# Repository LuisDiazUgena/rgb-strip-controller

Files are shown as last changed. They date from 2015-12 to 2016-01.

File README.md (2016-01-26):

# rgb-strip-controller

Rgb strip controller for WS2812 led stripes like Adafruit Neopixel.

Please check out <a href="#updates">updates</a> below.

# Hardware

It uses an Attiny 84 to run the code and a HC-06 bluetooth module to communicate with Bluetooth with an [app](https://github.com/LuisDiazUgena/Hack-A-Lamp/).

You can find a production board in [Hardware/For Manufacturing folder](https://github.com/LuisDiazUgena/rgb-strip-controller/tree/master/Hardware/For%20manufacturing)

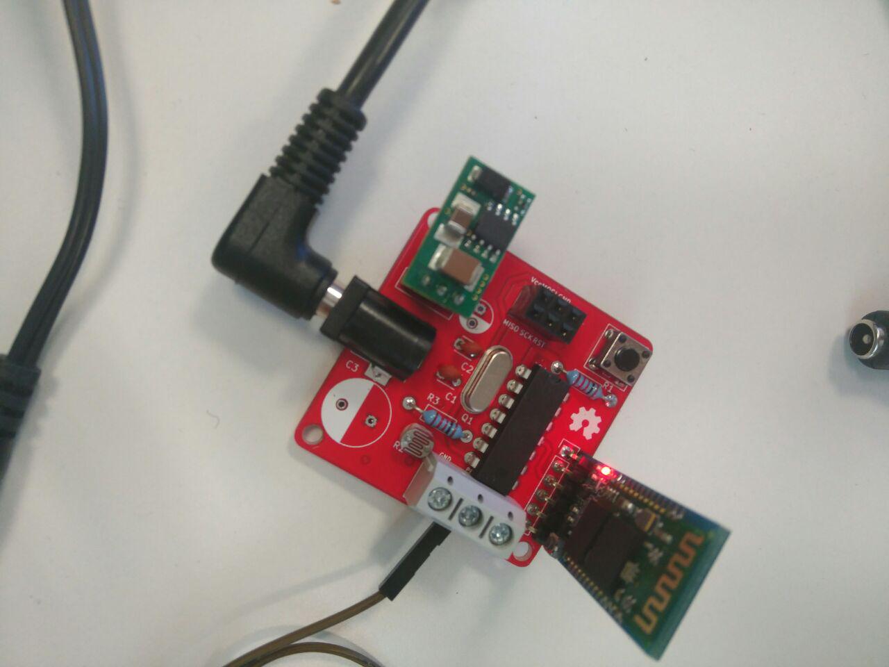
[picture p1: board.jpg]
PCB Layout


The board it's designed to be milled with [Cyclone](https://store.bq.com/es/cyclone), an open source CNC(Project [here](https://github.com/carlosgs/Cyclone-PCB-Factory)).

# Software

I've created a sketch that uses [Neopixel library by Adafruit](https://github.com/adafruit/Adafruit_NeoPixel) to control Neopixel strip.

You can find it under [rgb-strip-controller](https://github.com/LuisDiazUgena/rgb-strip-controller/tree/master/rgb-strip-controller) folder

## Usage

User Interface

Download the project and move .proto file to your smartphone (**recommended**) or tablet.

You can also open Protocoder file on your computer and copy it into an empty project on Protocoder web IDE.

**If your Arduino/Arduino cloned board/board doesn't have a Bluetooth module, you should connect a BT module and handle to receive data over BT-Serial.**

Upload *rgb-strip-controller.ino* file to your Arduino board.

Install protocoder apk on your device and then, with a file explorer, open *projects_Hack-a-lamp.proto* file with protocoder. Then run it on your device.

You **must** first pair your BT board or module to your device with bluetooth settings.

On protocoder interface click on Connect to Bluetooth and choose your board, wait until both BTs are connected and move the sliders, then click on Send to change the color.

**Auto send feature**: Use this is you want Protocoder send data color as you modify it. Using this feature provides a almost real time experience.

**On/Off switch**: When it's turned on, the color is set to white. When it's turned off, the color is set to black.

###<a name="updates">Updates</a>

**26-01-2016**

1. Recieved pcb boards and testing. It works!

**28-12-2015**

1. Finished sketch and tested on breadboard
2. Finished PCB layout
3. Created Gerbers
4. Created Gcodes

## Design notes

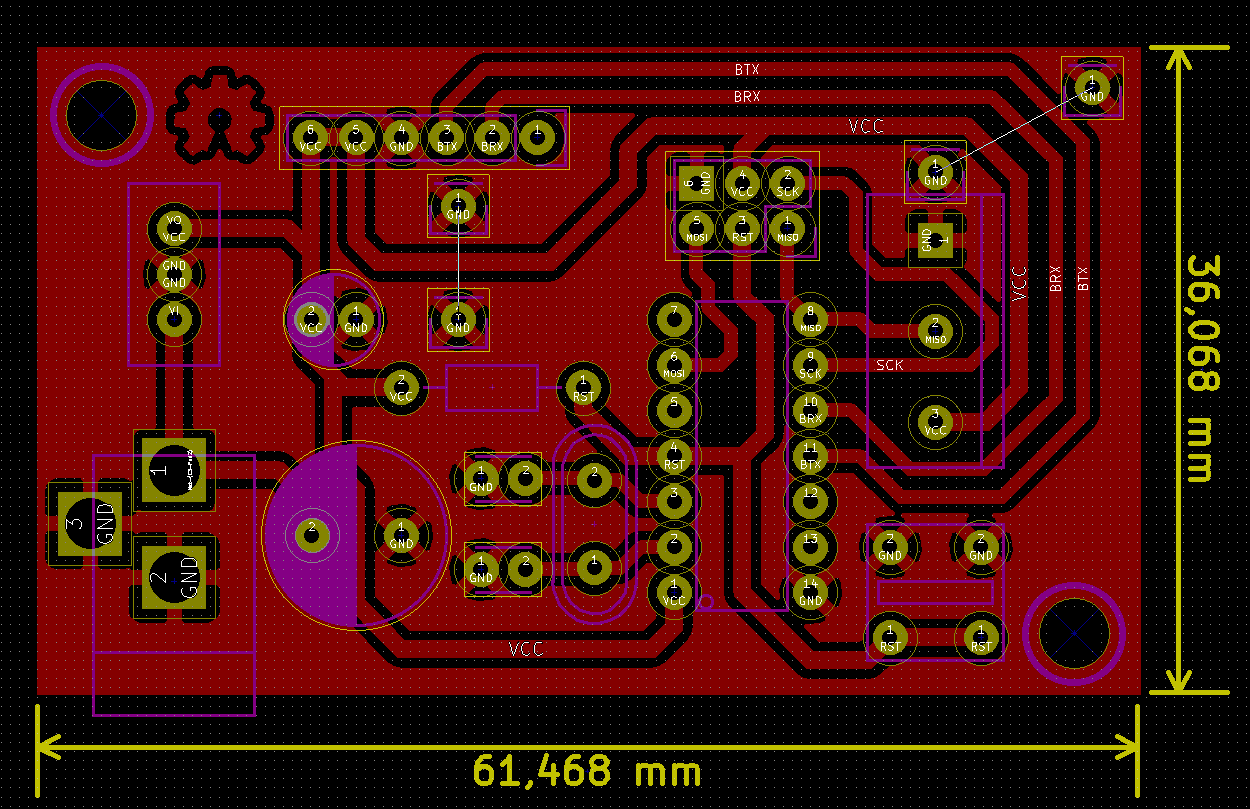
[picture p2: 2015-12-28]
pcb-layout.png

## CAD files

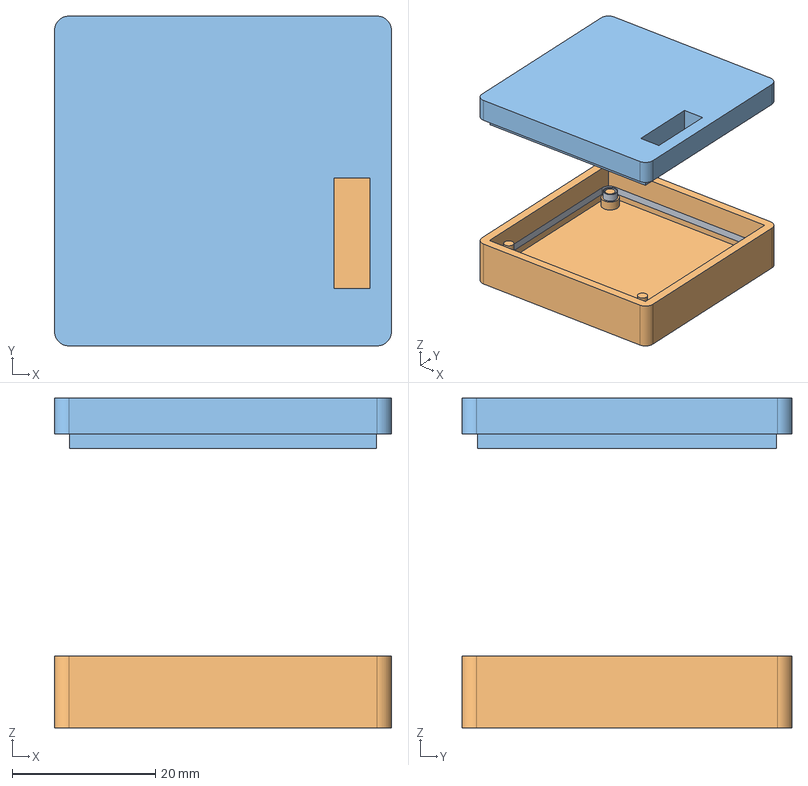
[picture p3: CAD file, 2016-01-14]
3D-Case/3D-Case V1.fcstd
47.0 x 46.0 x 46.0 mm
board
bottom_case

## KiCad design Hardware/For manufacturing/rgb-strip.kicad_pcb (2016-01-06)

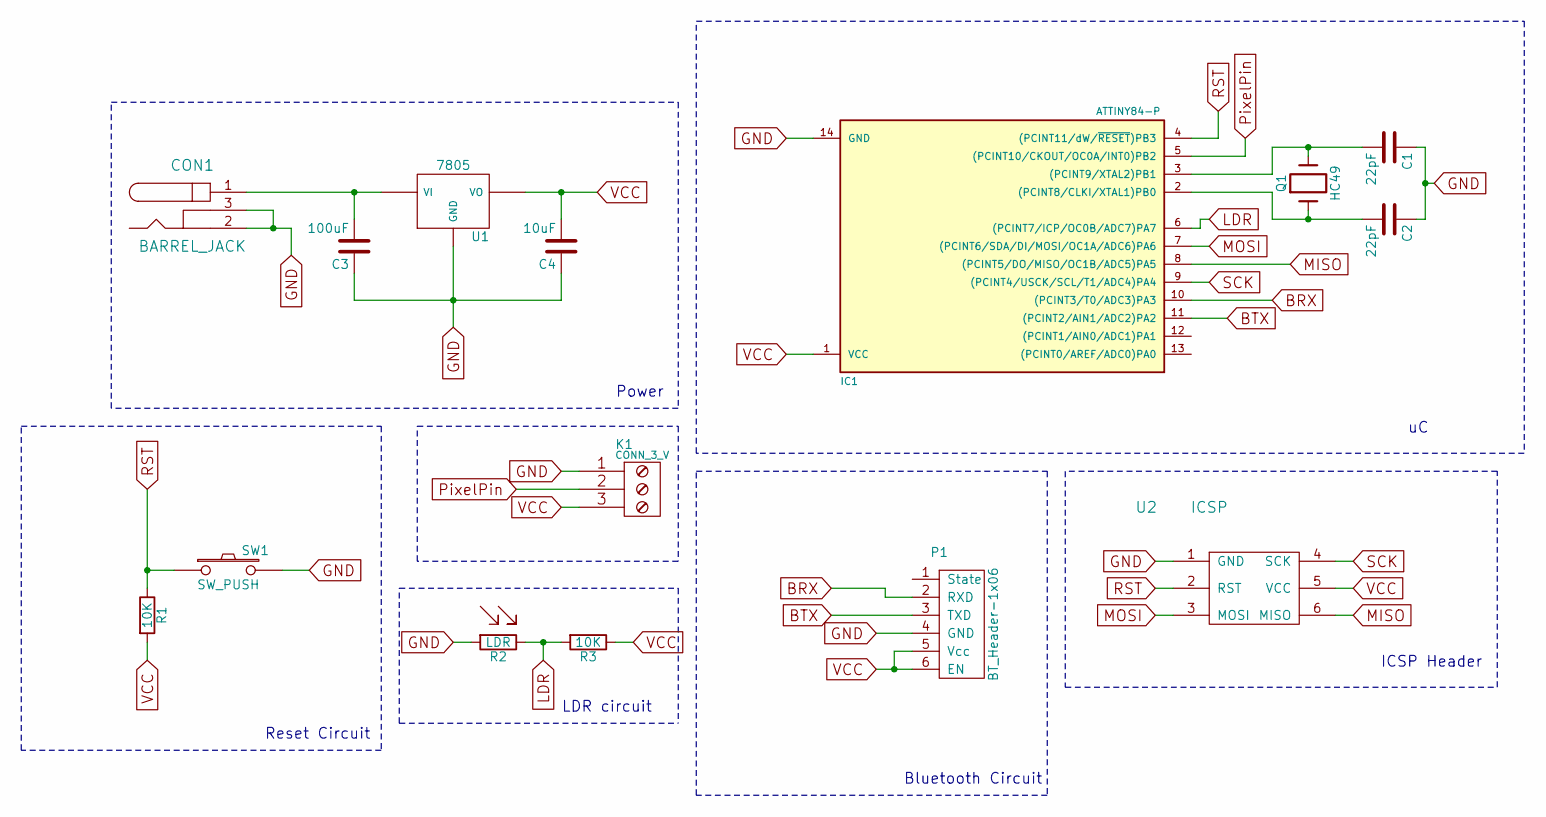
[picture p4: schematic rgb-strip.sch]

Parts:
C1, C2: 22pF; C_Disc_D3_P2.5
C3: 100uF; C_Radial_D10_L13_P5
C4: 10uF; C_Radial_D5_L6_P2.5
CON1: BARREL_JACK
IC1: ATTINY84-P; Attiny24-54-84
K1: CONN_3_V; bornier3
P1: BT_Header-1x06; Pin_Header_Straight_1x06
Q1: HC49; Crystal_HC49-U_Vertical
R1, R3: 10K; Resistor_Horizontal_RM10mm
R2: LDR
SW1: SW_PUSH
U1: 7805; LM7805
U2: ICSP; Pin_Header_Straight_2x03

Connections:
BRX: IC1.10 ((PCINT3/T0/ADC3)PA3), P1.2 (RXD)
BTX: IC1.11 ((PCINT2/AIN1/ADC2)PA2), P1.3 (TXD)
GND: C1.1, C2.1, C3.1, C4.1, CON1.2, CON1.3, IC1.14 (GND), K1.1, P1.4 (GND), R2.2, SW1.2, U1.GND, U2.1 (GND); also elsewhere on the board
LDR: IC1.6 ((PCINT7/ICP/OC0B/ADC7)PA7), R2.1, R3.2
MISO: IC1.8 ((PCINT5/DO/MISO/OC1B/ADC5)PA5), U2.6 (MISO); also elsewhere on the board
MOSI: IC1.7 ((PCINT6/SDA/DI/MOSI/OC1A/ADC6)PA6), U2.3 (MOSI); also elsewhere on the board
unnamed: C1.2, IC1.3 ((PCINT9/XTAL2)PB1), Q1.2
unnamed: C2.2, IC1.2 ((PCINT8/CLKI/XTAL1)PB0), Q1.1
unnamed: C3.2, CON1.1, U1.VI
PixelPin: IC1.5 ((PCINT10/CKOUT/OC0A/INT0)PB2), K1.2
RST: IC1.4 ((PCINT11/dW/~RESET~)PB3), R1.1, SW1.1, U2.2 (RST); also elsewhere on the board
SCK: IC1.9 ((PCINT4/USCK/SCL/T1/ADC4)PA4), U2.4 (SCK); also elsewhere on the board
VCC: C4.2, IC1.1 (VCC), K1.3, P1.5 (Vcc), P1.6 (EN), R1.2, R3.1, U1.VO, U2.5 (VCC); also elsewhere on the board

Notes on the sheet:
Power
Reset Circuit
Bluetooth Circuit
LDR circuit
ICSP Header

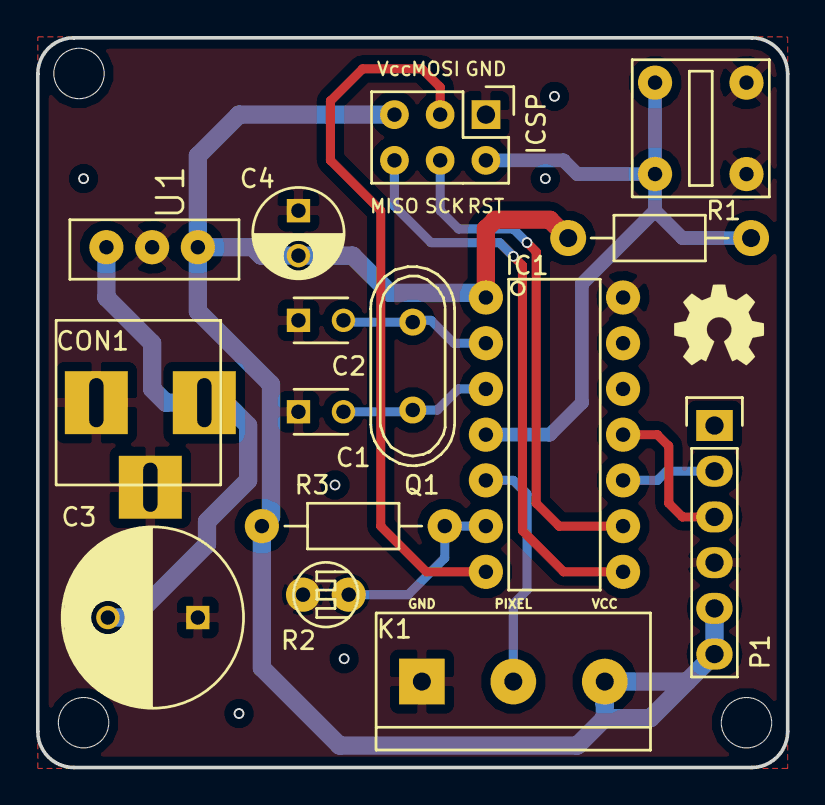
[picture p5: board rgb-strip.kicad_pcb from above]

Board: 2 copper layers, 41.7 x 40.5 mm, 15 parts (0 on the bottom side), 13 nets.

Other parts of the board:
ICSP: ICSP; Pin_Header_Straight_2x03

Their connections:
GND: ICSP.1; also elsewhere on the board
MISO: ICSP.6; also elsewhere on the board
MOSI: ICSP.3; also elsewhere on the board
RST: ICSP.2; also elsewhere on the board
SCK: ICSP.4; also elsewhere on the board
VCC: ICSP.5; also elsewhere on the board

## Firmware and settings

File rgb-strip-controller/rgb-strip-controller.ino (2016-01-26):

/*
  RGB strip controller

  Made by: Luis Diaz luisdiazugena@gmail.com

  https://github.com/LuisDiazUgena/rgb-strip-controller

*/

#include "SoftwareSerial.h"
#include "Adafruit_NeoPixel.h"

// Attiny D2 is pin 11
// Attiny D3 is pin 12
SoftwareSerial btSerial(2, 3); // 2 To TX 3 to RX

#define PIXEL_PIN 8
#define PIXEL_COUNT 26

Adafruit_NeoPixel strip = Adafruit_NeoPixel(PIXEL_COUNT, PIXEL_PIN, NEO_GRB + NEO_KHZ800);

int red = 0, green = 0, blue = 0;
int delayLed = 10;

boolean ldr = false;
boolean autoMode = false;
//int pinLDR = A7; //Attiny pin
int pinLDR = A0; //Arduino pin - just for test
long nextTime = 0;
int intervale = 1000;
int threshold = 500;

void setup() {

  pinMode(pinLDR, INPUT);

  //Serial.begin(19200);
  btSerial.begin(19200);
  strip.begin();
  delay(250);
  colorWipe(strip.Color(0, 0, 0), 0); // Turn off the strip
}

void loop() {
  //checkLDR();

  while (btSerial.available() > 0) {

    delayLed = btSerial.parseInt();
    red = btSerial.parseInt();
    green = btSerial.parseInt();
    blue = btSerial.parseInt();


    if (btSerial.read() == '\n') {

      red = constrain(red, 0, 255);
      green = constrain(green, 0, 255);
      blue = constrain(blue, 0, 255);

      colorWipe(strip.Color(red, green, blue), delayLed);
    }
  }
}

void colorWipe(uint32_t c, uint8_t wait) {
  for (uint16_t i = 0; i < strip.numPixels(); i++) {
    strip.setPixelColor(i, c);
    strip.show();
    delay(wait);
  }
  if (!autoMode) {
    btSerial.println("Color changed!");
  }
}
  void checkLDR() {
    int aktRead = analogRead(pinLDR);
    int color = map(aktRead, 0, 1023, 0, 255);

    btSerial.print(color);

    if (ldr && millis() > nextTime) {
      nextTime = millis() + intervale;
      if (autoMode) {
        // Change color automaticly using the ldr
        colorWipe(strip.Color(color, color, color), 0);
      } else {
        //turn on//off due a value
        if (ldr > threshold) {
          fadetoWhite();
        } else {
          fadetoBlack();
        }

      }
    }
  }

  void fadetoWhite() {
    for (int i = 0; i < 256; i++) {
      colorWipe(strip.Color(i, i, i), delayLed);
      delay(10);
    }
  }

  void fadetoBlack() {
    for (int i = 255; i >= 0; i--) {
      colorWipe(strip.Color(i, i, i), delayLed);
      delay(10);
    }
  }

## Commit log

2015-11-25 Finished inital board design
    [rgb-strip.kicad_pcb, rgb-strip.sch]
2015-12-02 Created pcb layout
    [_saved_rgb-strip.sch]
2015-12-02 pcb layout finished
    [_saved_rgb-strip.sch, rgb-strip.kicad_pcb, rgb-strip.sch]
2015-12-28 Added gerbers
    [rgb-strip-F.Cu.gbr, rgb-strip-NPTH.drl, rgb-strip.drl]
2015-12-28 Finished board
    [rgb-strip.kicad_pcb, rgb-strip.sch]
2015-12-28 Added pcb-layout file
2015-12-28 Added size info
    [rgb-strip.kicad_pcb]
2015-12-29 Moved to a folder
    [rgb-strip.kicad_pcb, rgb-strip.sch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]
2015-12-30 Added fan support
2015-12-30 Created board for manufacturing, including better specs
    [rgb-strip.kicad_pcb, rgb-strip.sch]
2016-01-03 Finished board - minor improvements - Removed fan support
    [rgb-strip-B.Adhes.gbr, rgb-strip-B.Cu.gbr, rgb-strip-B.Mask.gbr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]
2016-01-03 Removed fan support - Started to work on ldr support
2016-01-06 Improved design and updated gerbers
    [rgb-strip-B.Adhes.gbr, rgb-strip-B.Cu.gbr, rgb-strip-B.Mask.gbr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]
2016-01-12 Bottom case created
    [3D-Case V1.fcstd]
2016-01-14 Started to work on a 3D printed case to hold the project
    [3D-Case V1.fcstd]
2016-01-26 Added picture of the board
